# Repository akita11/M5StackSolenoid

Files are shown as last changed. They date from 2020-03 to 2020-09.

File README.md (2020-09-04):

# M5StackSolenoid

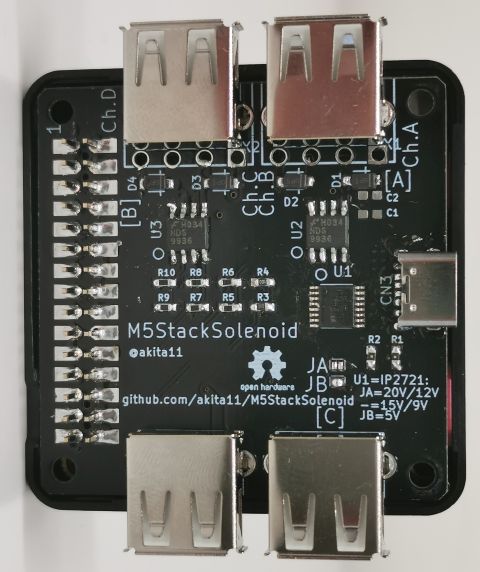
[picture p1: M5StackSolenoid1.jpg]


ソレノイド（[タカハの5Vソレノイド](http://takaha.co.jp/co/product-ss#productWrapSec1)など）を制御するM5Stack用の拡張基板です。
最大4個のソレノイドをON/OFF制御できます。

# 機能

実装するコネクタ・部品によって、以下の2通りの使い方ができます。
- [使い方1] USBコネクタ実装（[タカハの5Vソレノイド](http://takaha.co.jp/co/product-ss#productWrapSec1)用）：以下のようになります
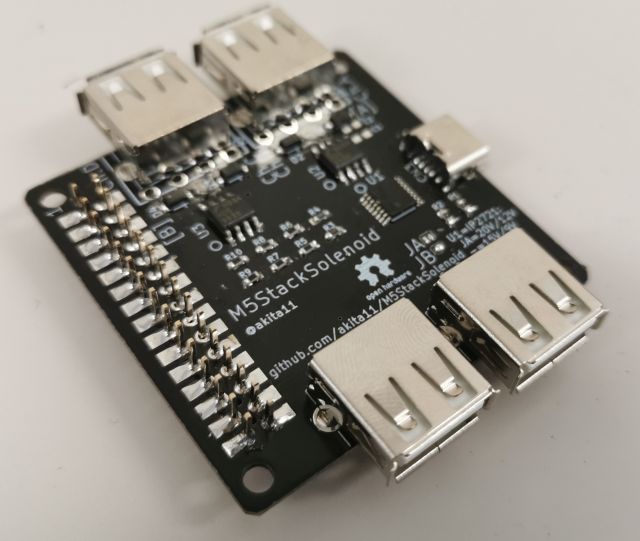
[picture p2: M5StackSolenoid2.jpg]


- [使い方2] 2.ネジ端子実装（一般のソレノイド）：以下のようになります
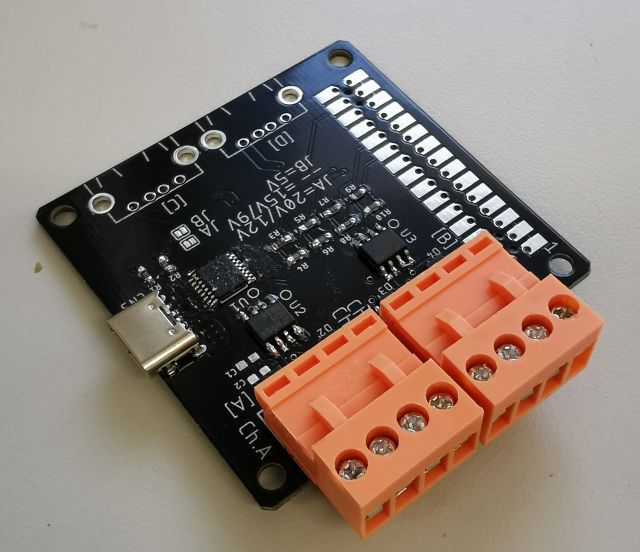
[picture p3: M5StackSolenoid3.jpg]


※[スイッチサイエンスで託販売しているもの](https://www.switch-science.com/catalog/6328/)（5Vソレノイド用のショートピン端子が5個付属しています）は、「使い方1」の状態のものです。

# 用意するもの
- M5Stack (Core/Gray等のCore系、またはCore2)
- USB Type-C端子のある電源（ACアダプタ、モバイルバッテリ等。ソレノイド駆動用の電源）
- ソレノイド（用いているnMOS、ダイオードの定格内のものを用いてください）
  - [使い方1] [タカハの5Vソレノイド](http://takaha.co.jp/co/product-ss#productWrapSec1)、microUSBケーブル、[ショートピン端子](http://akizukidenshi.com/catalog/g/gP-03687/)※「タカハの5Vソレノイド」に「ショートピン端子」を差し込んだ状態で使用します
  - [使い方2] ソレノイド、ネジ端子[HT396R-4P](https://ja.aliexpress.com/item/33027266661.html)、IP2721（USB PDで5V以外の電圧をソレノイド駆動に用いる場合：IP2721の使い方の詳細はIP2721のデータシートを参照してください）

# 使い方
1. M5Stackの本体(Core、底板を外した状態)に本ボードを差し込み、USB Type-C端子に電源をつなぎます。
1. M5Stackの以下のGPIOピンに1を与えるとソレノイドがONに、0を与えるとOFFになります。（M5Stackのプログラムは、ArduinoIDE、UI Flow等で開発できます）使用例としてtest.m5f (UI Flowプログラム）を参照してください。
   - Ch.A : GPIO26
   - Ch.B : GPIO12 (Core2ではGPIO27)
   - Ch.C : GPIO13 (Core2ではGPIO19)
   - Ch.D : GPIO5 (Core2ではGPIO33)

※なおソレノイドの番号は、[使い方1]の場合は基板上の[A]-[D]で表示されているUSBコネクタに対応します。[使い方2]の場合は、基板上の"Ch.A"-"Ch.D"の表示に対応し、1つのネジ端子(HT396R)に2個のソレノイドを接続できます。

# Author

Junichi Akita (@akita11, akita@ifdl.jp)

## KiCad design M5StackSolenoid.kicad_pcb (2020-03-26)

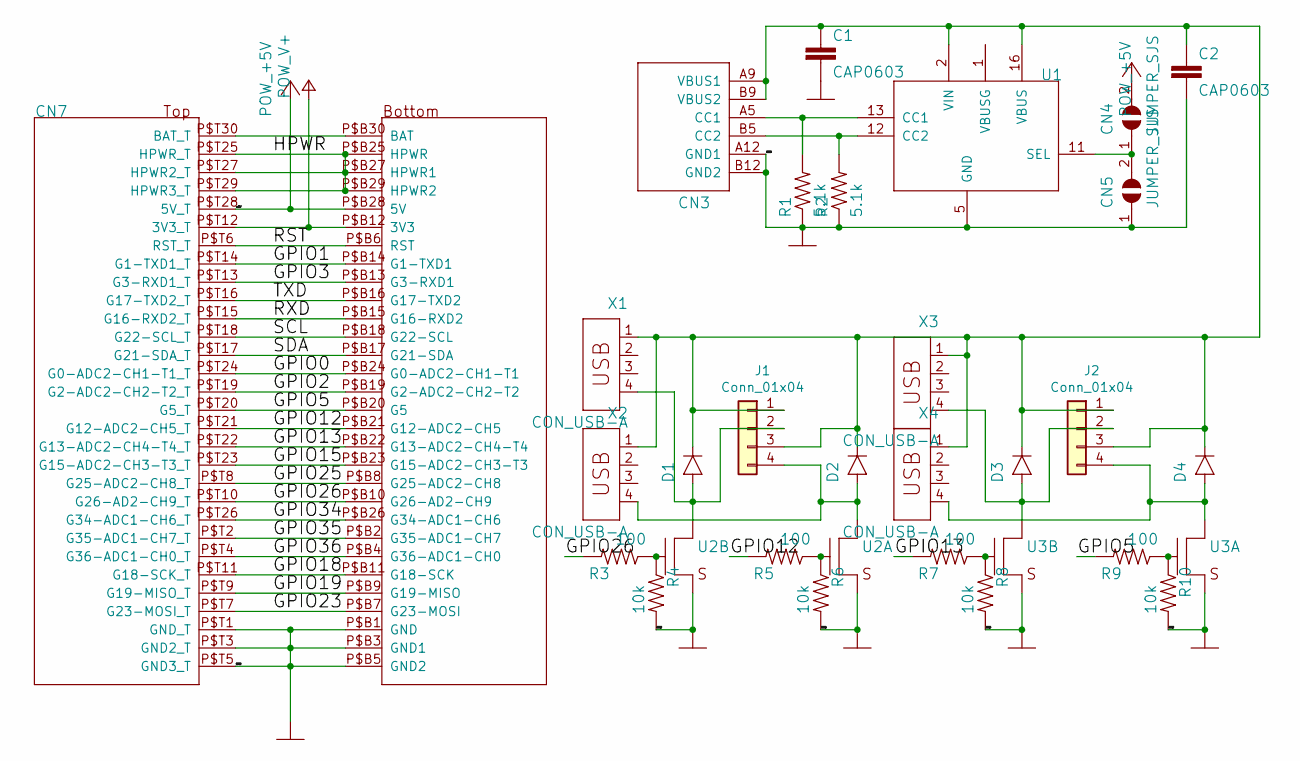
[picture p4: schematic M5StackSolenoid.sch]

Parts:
C1, C2: CAP0603; 0603
CN3: CON_USB-C-6; USB-C_6P
CN4, CN5: JUMPER_SJS
CN7: MBUS_SEPNOHOLE; MBUS_SEP_NOHOLENOTCH
D1, D2, D3, D4: DIODESOD123FL; SOD123FL
J1, J2: Conn_01x04; CON_HT396R_4P
R1, R2: 5.1k; 0603
R3, R5, R7, R9: 100; 0603
R4, R6, R8, R10: 10k; 0603
U1: PMC_IP2721; TSSOP16
U2, U3: TR_NMOS_IRF7103; SO08
X1, X2, X3, X4: CON_USB-A; USB-A

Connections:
+5V: CN4.2, CN7.P$B28 (5V), CN7.P$T28 (5V_T)
/GPIO0: CN7.P$B24 (G0-ADC2-CH1-T1), CN7.P$T24 (G0-ADC2-CH1-T1_T)
/GPIO1: CN7.P$B14 (G1-TXD1), CN7.P$T14 (G1-TXD1_T)
/GPIO2: CN7.P$B19 (G2-ADC2-CH2-T2), CN7.P$T19 (G2-ADC2-CH2-T2_T)
/GPIO3: CN7.P$B13 (G3-RXD1), CN7.P$T13 (G3-RXD1_T)
/GPIO5: CN7.P$B20 (G5), CN7.P$T20 (G5_T), R9.2
/GPIO12: CN7.P$B21 (G12-ADC2-CH5), CN7.P$T21 (G12-ADC2-CH5_T), R5.2
/GPIO13: CN7.P$B22 (G13-ADC2-CH4-T4), CN7.P$T22 (G13-ADC2-CH4-T4_T), R7.2
/GPIO15: CN7.P$B23 (G15-ADC2-CH3-T3), CN7.P$T23 (G15-ADC2-CH3-T3_T)
/GPIO18: CN7.P$B11 (G18-SCK), CN7.P$T11 (G18-SCK_T)
/GPIO19: CN7.P$B9 (G19-MISO), CN7.P$T9 (G19-MISO_T)
/GPIO23: CN7.P$B7 (G23-MOSI), CN7.P$T7 (G23-MOSI_T)
/GPIO25: CN7.P$B8 (G25-ADC2-CH8), CN7.P$T8 (G25-ADC2-CH8_T)
/GPIO26: CN7.P$B10 (G26-AD2-CH9), CN7.P$T10 (G26-AD2-CH9_T), R3.2
/GPIO34: CN7.P$B26 (G34-ADC1-CH6), CN7.P$T26 (G34-ADC1-CH6_T)
/GPIO35: CN7.P$B2 (G35-ADC1-CH7), CN7.P$T2 (G35-ADC1-CH7_T)
/GPIO36: CN7.P$B4 (G36-ADC1-CH0), CN7.P$T4 (G36-ADC1-CH0_T)
/HPWR: CN7.P$B25 (HPWR), CN7.P$B27 (HPWR1), CN7.P$B29 (HPWR2), CN7.P$T25 (HPWR_T), CN7.P$T27 (HPWR2_T), CN7.P$T29 (HPWR3_T)
/RST: CN7.P$B6 (RST), CN7.P$T6 (RST_T)
/RXD: CN7.P$B15 (G16-RXD2), CN7.P$T15 (G16-RXD2_T)
/SCL: CN7.P$B18 (G22-SCL), CN7.P$T18 (G22-SCL_T)
/SDA: CN7.P$B17 (G21-SDA), CN7.P$T17 (G21-SDA_T)
/TXD: CN7.P$B16 (G17-TXD2), CN7.P$T16 (G17-TXD2_T)
GND: C1.2, C2.2, CN3.A12 (GND1), CN3.B12 (GND2), CN5.1, CN7.P$B1 (GND), CN7.P$B3 (GND1), CN7.P$B5 (GND2), CN7.P$T1 (GND_T), CN7.P$T3 (GND2_T), CN7.P$T5 (GND3_T), R1.1, R2.1, R4.2, R6.2, R8.2, R10.2, U1.5 (GND), U2.1 (S), U2.3 (S), U3.1 (S), U3.3 (S)
unnamed: C1.1, C2.1, CN3.A9 (VBUS1), CN3.B9 (VBUS2), D1.P$K, D2.P$K, D3.P$K, D4.P$K, J1.1, J1.3, J2.1, J2.3, U1.2 (VIN), U1.16 (VBUS), X1.1, X2.1, X3.1, X4.1
unnamed: CN3.A5 (CC1), R1.2, U1.13 (CC1)
unnamed: CN3.B5 (CC2), R2.2, U1.12 (CC2)
unnamed: CN4.1, CN5.2, U1.11 (SEL)
unnamed: CN7.P$B30 (BAT), CN7.P$T30 (BAT_T)
unnamed: D1.P$A, J1.2, U2.5 (D), X1.4
unnamed: D2.P$A, J1.4, U2.7 (D), X2.4
unnamed: D3.P$A, J2.2, U3.5 (D), X3.4
unnamed: D4.P$A, J2.4, U3.7 (D), X4.4
unnamed: R3.1, R4.1, U2.4 (G)
unnamed: R5.1, R6.1, U2.2 (G)
unnamed: R7.1, R8.1, U3.4 (G)
unnamed: R9.1, R10.1, U3.2 (G)
V+: CN7.P$B12 (3V3), CN7.P$T12 (3V3_T)

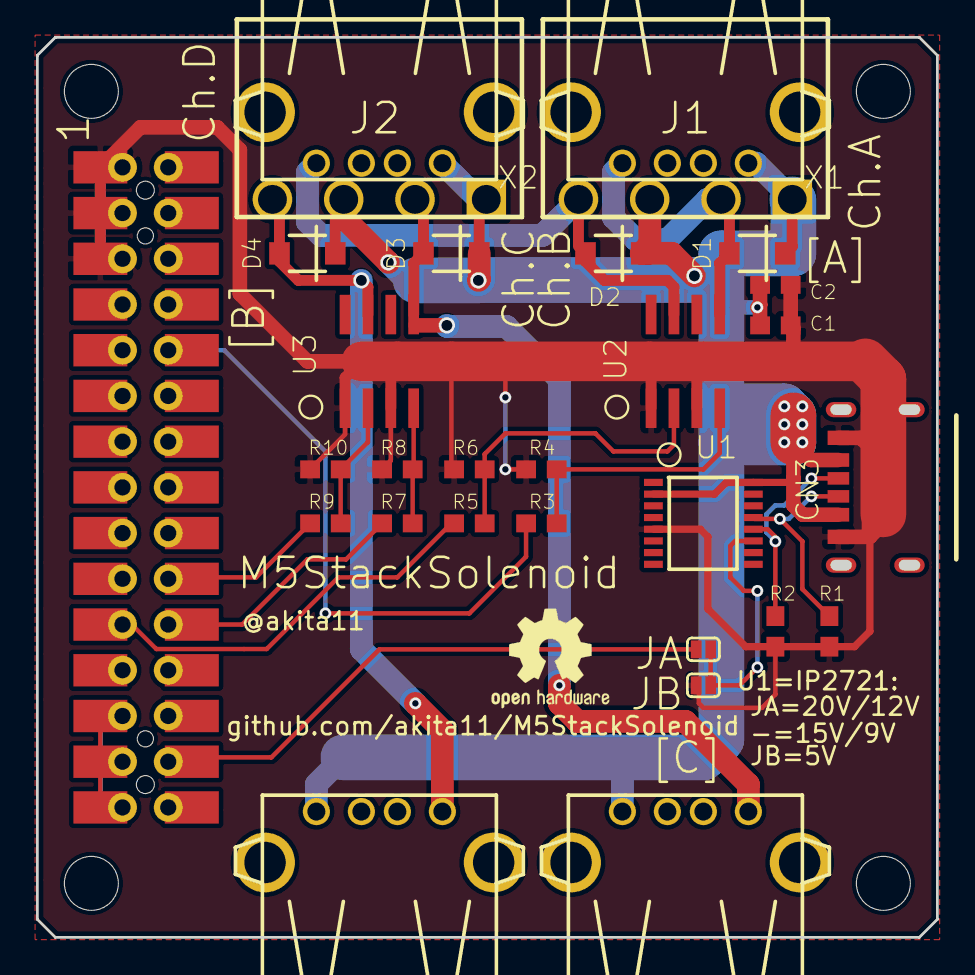
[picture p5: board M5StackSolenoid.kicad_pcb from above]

Board: 2 copper layers, 50.0 x 50.0 mm, 29 parts (0 on the bottom side), 38 nets.

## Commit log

2020-03-26 ファイル一式とREADMEを追加
    [M5StackSolenoid.kicad_pcb, M5StackSolenoid.sch]
2020-04-08 UIFlow用テストプログラムを追加
2020-06-09 readmeに5Vソレノイドのショートピンについて追記
2020-06-09 readmeに追記
2020-09-04 Core2の情報を記載
